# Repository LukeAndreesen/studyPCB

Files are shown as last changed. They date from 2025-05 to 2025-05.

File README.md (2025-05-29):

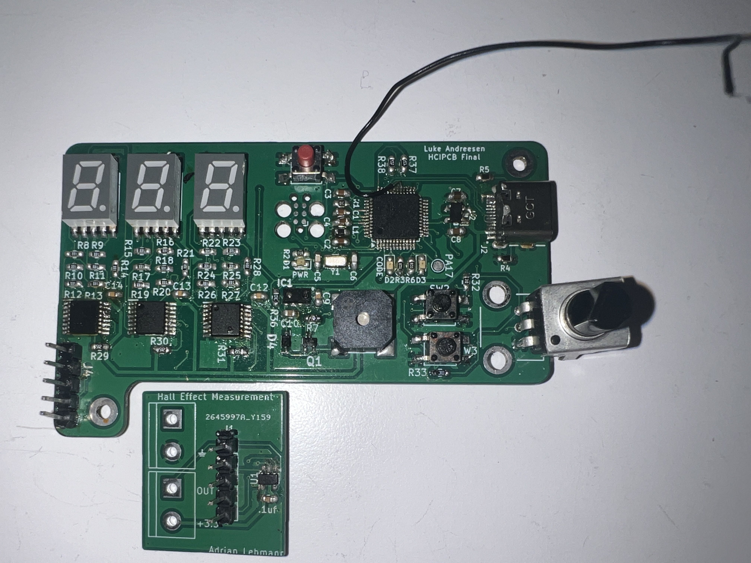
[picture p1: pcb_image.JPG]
PCB Image


This project is a study timer that is meant to enforce productivity; an onboard
IR sensor, as well as a daughter-board hall-effect sensor module detect
a user's presence and ensure their phone is sitting on the desk and not in 
their hands. 3 daisy-chaineed shift registers control the 7-segment displays, 
and a magnetic buzzer and onboard LED's provide feedback and alerts. The 
devce connects to the user's computer via USB for power and serial connectivity
with the UI which can be interacted with using the board's buttons and 
potentiometer dial. This was my first independent PCB board, and I really
enjoyed the process of designing, soldering, and programming it!

A Bill of Materials is available as CSV in this repo, along with KiCad schematics.

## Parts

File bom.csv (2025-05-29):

Reference | Value | Datasheet | Footprint | Qty | DNP
C1,C2,C3,C4 | 0.1uF | ~ | Capacitor_SMD:C_0603_1608Metric_Pad1.08x0.95mm_HandSolder | 4
C5,C6 | 22pF | ~ | Capacitor_SMD:C_0603_1608Metric_Pad1.08x0.95mm_HandSolder | 2
C7,C8 | 1uF | ~ | Capacitor_SMD:C_0603_1608Metric_Pad1.08x0.95mm_HandSolder | 2
C9,C12,C13,C14 | 100nF | ~ | Capacitor_SMD:C_0603_1608Metric_Pad1.08x0.95mm_HandSolder | 4
C10 | 470nF | ~ | Capacitor_SMD:C_0603_1608Metric_Pad1.08x0.95mm_HandSolder | 1
C15 | 100nF | ~ | Capacitor_SMD:C_0603_1608Metric_Pad1.08x0.95mm_HandSolder | 1 | DNP
D1 | GREEN | ~ | LED_SMD:LED_0603_1608Metric_Pad1.05x0.95mm_HandSolder | 1
D2,D3 | RED | ~ | LED_SMD:LED_0603_1608Metric_Pad1.05x0.95mm_HandSolder | 2
D4 | D | https://www.vishay.com/docs/85751/1n4148ws.pdf | finalpcb:SOD2713X115N | 1
DS1,DS2,DS3 | 157112V12700 | https://componentsearchengine.com/Datasheets/2/157112V12700.pdf | finalpcb:157112V12700 | 3
IC1 | VCNL3040 | https://www.vishay.com/docs/84917/vcnl3040.pdf | finalpcb:SON108P200X400X115-8N | 1
IC2,IC3,IC4 | 74HC595PW-Q100,118 | https://assets.nexperia.com/documents/data-sheet/74HC_HCT595_Q100.pdf | finalpcb:SOP65P640X110-16N | 3
IC5 | Si7210-B-04-IVR | https://componentsearchengine.com/Datasheets/2/SI7210-B-04-IVR.pdf | finalpcb:SOT95P275X125-5N | 1 | DNP
J1 | SWD_TAG-CONNECT | https://www.tag-connect.com/wp-content/uploads/bsk-pdf-manager/TC2030-CTX_1.pdf | Connector:Tag-Connect_TC2030-IDC-FP_2x03_P1.27mm_Vertical | 1
J2 | USB4105-GF-A | https://www.mouser.com/datasheet/2/837/Global_Connector_Technology_usb4105-3106202.pdf | hcipcb:GCT_USB4105-GF-A | 1
J4 | 10129379-905001BLF | https://cdn.amphenol-cs.com/media/wysiwyg/files/drawing/10129379.pdf | HDRRA5W67P0X254_1X5_1270X254X241P | 1
L1 | FB-30R | https://www.mouser.com/ProductDetail/Laird-Performance-Materials/MI0603K300R-10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 | Inductor_SMD:L_0603_1608Metric_Pad1.05x0.95mm_HandSolder | 1
LS3 | CMT-8504-03-SMT-TR | https://www.sameskydevices.com/product/resource/cmt-8504-03-smt-tr.pdf | CMT850403SMTTR | 1
PA17 | TestPoint | ~ | TestPoint:TestPoint_Pad_D1.5mm | 1
Q1 | Q_NPN_BCE | https://www.mouser.com/datasheet/2/408/2SA1588_datasheet_en_20210625-1140114.pdf | finalpcb:2SA1588GRLF | 1
R1,R32,R33,R36 | 10k | ~ | Resistor_SMD:R_0603_1608Metric_Pad0.98x0.95mm_HandSolder | 4
R2,R3,R6 | 1k | ~ | Resistor_SMD:R_0603_1608Metric_Pad0.98x0.95mm_HandSolder | 3
R4,R5,R29,R30,R31 | 5.1k | ~ | Resistor_SMD:R_0603_1608Metric_Pad0.98x0.95mm_HandSolder | 5
R7 | 180 | ~ | Resistor_SMD:R_0603_1608Metric_Pad0.98x0.95mm_HandSolder | 1
R8,R9,R10,R11,R12,R13,R14,R15,R16,R17,R18,R19,R20,R21,R22,R23,R24,R25,R26,R27,R28 | 330 | ~ | Resistor_SMD:R_0603_1608Metric_Pad0.98x0.95mm_HandSolder | 21
R37,R38 | 4.7k | ~ | Resistor_SMD:R_0603_1608Metric_Pad0.98x0.95mm_HandSolder | 2
SW1,SW2,SW3 | SW_Push | ~ | Button_Switch_SMD:SW_SPST_TL3305A | 3
U1 | ATSAMD21G18A-A | http://ww1.microchip.com/downloads/en/DeviceDoc/SAM_D21_DA1_Family_Data%20Sheet_DS40001882E.pdf | Package_QFP:TQFP-48_7x7mm_P0.5mm | 1
U2 | TLV73333PQDBVRQ1 | http://www.ti.com/lit/gpn/TLV733P-Q1 | hcipcb:SOT95P280X145-5N | 1
VR1 | PT01-B115D-B103 | https://www.sameskydevices.com/product/resource/supplyframepdf/pt01-b120d-b103.pdf | finalpcb:PT01B115DB103 | 1
Y1 | Crystal_Small | ~ | Crystal:Crystal_SMD_3215-2Pin_3.2x1.5mm | 1

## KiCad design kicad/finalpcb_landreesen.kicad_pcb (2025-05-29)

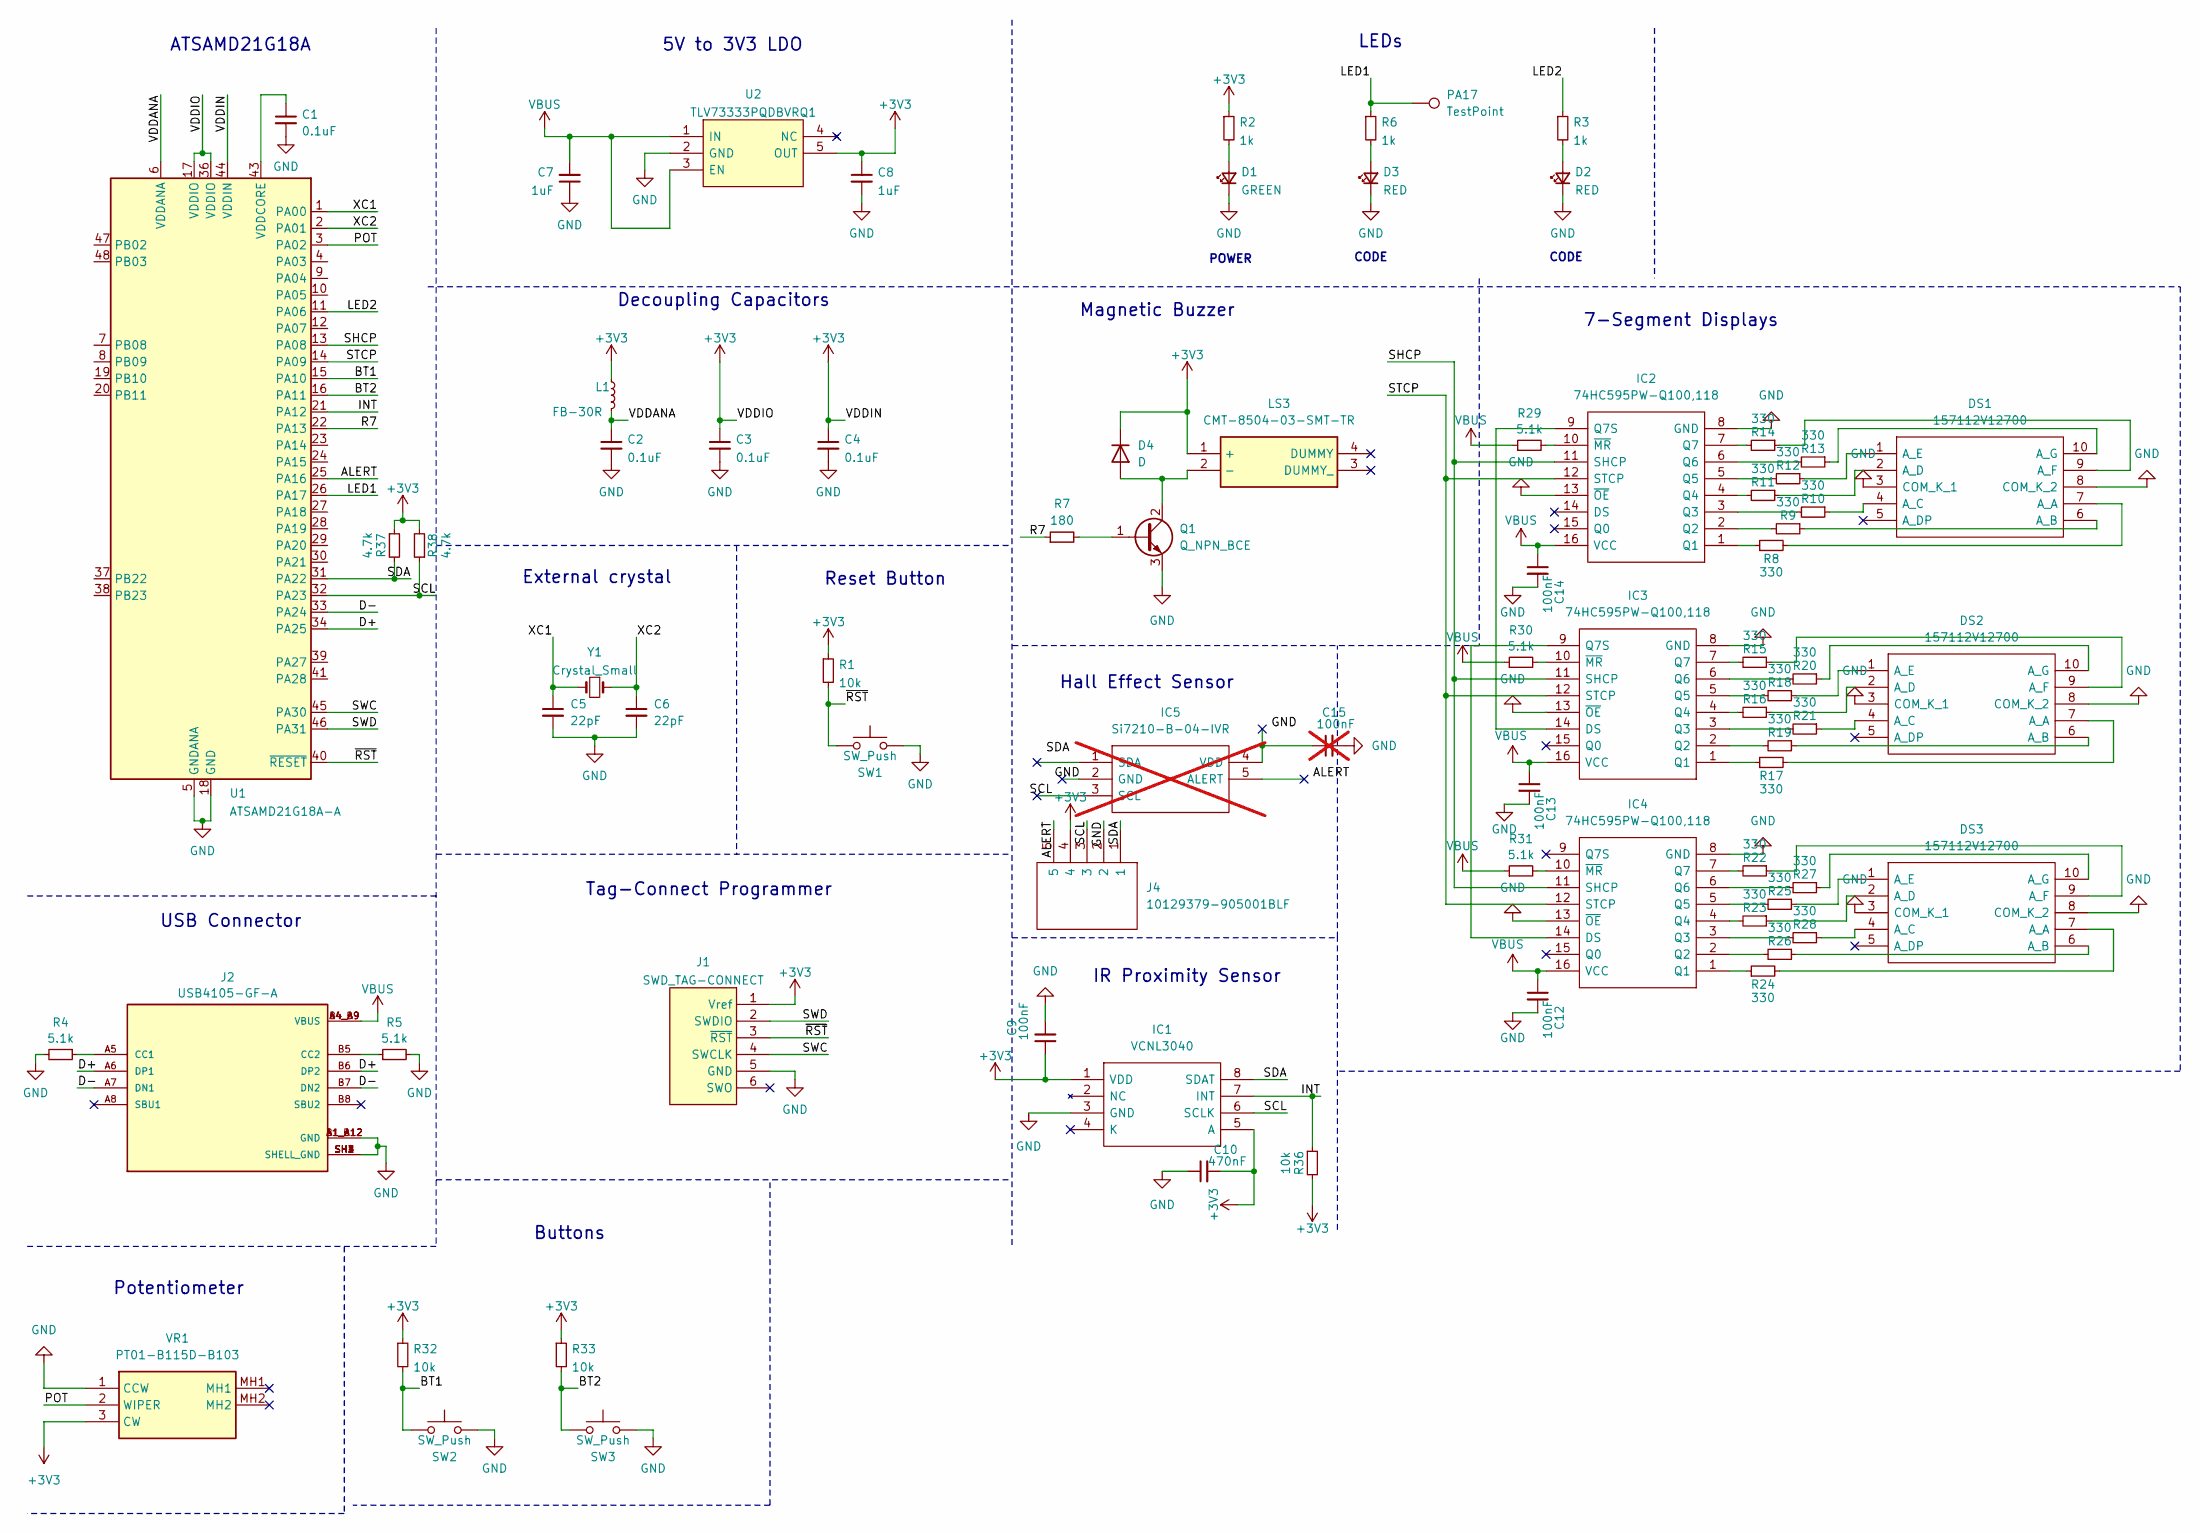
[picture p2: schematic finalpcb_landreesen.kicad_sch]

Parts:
C1, C2, C3, C4: 0.1uF; C_0603_1608Metric_Pad1.08x0.95mm_HandSolder
C5, C6: 22pF; C_0603_1608Metric_Pad1.08x0.95mm_HandSolder; Mouser Part Number 581-06035C220JAT2A
C7, C8: 1uF; C_0603_1608Metric_Pad1.08x0.95mm_HandSolder
C9, C12, C13, C14: 100nF; C_0603_1608Metric_Pad1.08x0.95mm_HandSolder
C10: 470nF; C_0603_1608Metric_Pad1.08x0.95mm_HandSolder
C15: 100nF; C_0603_1608Metric_Pad1.08x0.95mm_HandSolder; not fitted
D1: GREEN; LED_0603_1608Metric_Pad1.05x0.95mm_HandSolder
D2, D3: RED; LED_0603_1608Metric_Pad1.05x0.95mm_HandSolder; Mouser Part Number 710-150060RS55040
D4: D; SOD2713X115N
DS1, DS2, DS3: 157112V12700; Mouser Part Number 710-157112V12700
IC1: VCNL3040; SON108P200X400X115-8N; Mouser Part Number 78-VCNL3040
IC2, IC3, IC4: 74HC595PW-Q100,118; SOP65P640X110-16N; Mouser Part Number 771-74HC595PW-Q100
IC5: Si7210-B-04-IVR; SOT95P275X125-5N; Mouser Part Number 634-SI7210-B-04-IVR; not fitted
J1: SWD_TAG-CONNECT; Tag-Connect_TC2030-IDC-FP_2x03_P1.27mm_Vertical
J2: USB4105-GF-A; GCT_USB4105-GF-A
J4: 10129379-905001BLF; HDRRA5W67P0X254_1X5_1270X254X241P; Manufacturer_Part_Number 10129379-905001BLF
L1: FB-30R; L_0603_1608Metric_Pad1.05x0.95mm_HandSolder
LS3: CMT-8504-03-SMT-TR; CMT850403SMTTR; Mouser Part Number 179-CMT-8504-03SMTTR
PA17: TestPoint; TestPoint_Pad_D1.5mm
Q1: Q_NPN_BCE; 2SA1588GRLF
R1, R32, R33, R36: 10k; R_0603_1608Metric_Pad0.98x0.95mm_HandSolder
R2, R3, R6: 1k; R_0603_1608Metric_Pad0.98x0.95mm_HandSolder
R4, R5, R29, R30, R31: 5.1k; R_0603_1608Metric_Pad0.98x0.95mm_HandSolder
R7: 180; R_0603_1608Metric_Pad0.98x0.95mm_HandSolder
R8, R9, R10, R11, R12, R13, R14, R15, R16, R17, R18, R19, R20, R21, R22, R23, R24, R25, R26, R27, R28: 330; R_0603_1608Metric_Pad0.98x0.95mm_HandSolder
R37, R38: 4.7k; R_0603_1608Metric_Pad0.98x0.95mm_HandSolder
SW1, SW2, SW3: SW_Push; SW_SPST_TL3305A
U1: ATSAMD21G18A-A; TQFP-48_7x7mm_P0.5mm
U2: TLV73333PQDBVRQ1; SOT95P280X145-5N; Mouser Part Number 595-TLV73333PQDBVRQ1
VR1: PT01-B115D-B103; PT01B115DB103; Mouser Part Number 179-PT01-B115D-B103
Y1: Crystal_Small; Crystal_SMD_3215-2Pin_3.2x1.5mm; Mouser Part Number 815-ABS07-32.768KHZT

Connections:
+3V3: C3.1, C4.1, C8.1, C9.1, C10.2, D4.1 (K), IC1.1 (VDD), IC1.5 (A), J1.1 (Vref), J4.4, L1.1, LS3.1 (+), R1.1, R2.1, R32.1, R33.1, R36.2, R37.1, R38.2, U1.17 (VDDIO), U1.36 (VDDIO), U1.44 (VDDIN), U2.5 (OUT), VR1.3 (CW)
/ALERT: J4.5, U1.25 (PA16)
/BT1: R32.2, SW2.1, U1.15 (PA10)
/BT2: R33.2, SW3.1, U1.16 (PA11)
/D+: J2.A6 (DP1), J2.B6 (DP2), U1.34 (PA25)
/D-: J2.A7 (DN1), J2.B7 (DN2), U1.33 (PA24)
/INT: IC1.7 (INT), R36.1, U1.21 (PA12)
/LED1: PA17.1, R6.1, U1.26 (PA17)
/LED2: R3.1, U1.11 (PA06)
/POT: U1.3 (PA02), VR1.2 (WIPER)
/R7: R7.1, U1.22 (PA13)
/SCL: IC1.6 (SCLK), J4.3, R38.1, U1.32 (PA23)
/SDA: IC1.8 (SDAT), J4.1, R37.2, U1.31 (PA22)
/SHCP: IC2.11 (SHCP), IC3.11 (SHCP), IC4.11 (SHCP), U1.13 (PA08)
/STCP: IC2.12 (STCP), IC3.12 (STCP), IC4.12 (STCP), U1.14 (PA09)
/SWC: J1.4 (SWCLK), U1.45 (PA30)
/SWD: J1.2 (SWDIO), U1.46 (PA31)
/VDDANA: C2.1, L1.2, U1.6 (VDDANA)
/XC1: C5.1, U1.1 (PA00), Y1.2
/XC2: C6.1, U1.2 (PA01), Y1.1
/~RST: J1.3 (~RST), R1.2, SW1.1, U1.40 (~RESET)
GND: C1.2, C2.2, C3.2, C4.2, C5.2, C6.2, C7.1, C8.2, C9.2, C10.1, C12.2, C13.2, C14.2, C15.2, D1.1 (K), D2.1 (K), D3.1 (K), DS1.3 (COM_K_1), DS1.8 (COM_K_2), DS2.3 (COM_K_1), DS2.8 (COM_K_2), DS3.3 (COM_K_1), DS3.8 (COM_K_2), IC1.3 (GND), IC2.8 (GND), IC2.13 (~OE), IC3.8 (GND), IC3.13 (~OE), IC4.8 (GND), IC4.13 (~OE), J1.5 (GND), J2.A1_B12 (GND), J2.B1_A12 (GND), J2.SH1 (SHELL_GND), J2.SH2 (SHELL_GND), J2.SH3 (SHELL_GND), J2.SH4 (SHELL_GND), J4.2, Q1.3 (E), R4.2, R5.2, SW1.2, SW2.2, SW3.2, U1.5 (GNDANA), U1.18 (GND), U1.35 (GND), U1.42 (GND), U2.2 (GND), VR1.1 (CCW)
unnamed: C15.1, IC5.4 (VDD)
unnamed: D1.2 (A), R2.2
unnamed: D2.2 (A), R3.2
unnamed: D3.2 (A), R6.2
unnamed: D4.2 (A), LS3.2 (-), Q1.2 (C)
unnamed: DS1.7 (A_A), R8.2
unnamed: DS1.6 (A_B), R9.1
unnamed: DS1.4 (A_C), R10.1
unnamed: DS1.2 (A_D), R11.1
unnamed: DS1.1 (A_E), R12.1
unnamed: DS1.9 (A_F), R14.1
unnamed: DS1.10 (A_G), R13.1
unnamed: DS2.7 (A_A), R17.2
unnamed: DS2.6 (A_B), R19.1
unnamed: DS2.4 (A_C), R21.1
unnamed: DS2.2 (A_D), R16.1
unnamed: DS2.1 (A_E), R18.1
unnamed: DS2.9 (A_F), R15.1
unnamed: DS2.10 (A_G), R20.1
unnamed: DS3.7 (A_A), R24.2
unnamed: DS3.6 (A_B), R26.1
unnamed: DS3.4 (A_C), R28.1
unnamed: DS3.2 (A_D), R23.1
unnamed: DS3.1 (A_E), R25.1
unnamed: DS3.9 (A_F), R22.1
unnamed: DS3.10 (A_G), R27.1
unnamed: IC2.1 (Q1), R8.1
unnamed: IC2.2 (Q2), R9.2
unnamed: IC2.3 (Q3), R10.2
unnamed: IC2.4 (Q4), R11.2
unnamed: IC2.5 (Q5), R12.2
unnamed: IC2.6 (Q6), R13.2
unnamed: IC2.7 (Q7), R14.2
unnamed: IC2.9 (Q7S), IC3.14 (DS)
unnamed: IC2.10 (~MR), R29.2
unnamed: IC3.1 (Q1), R17.1
unnamed: IC3.2 (Q2), R19.2
unnamed: IC3.3 (Q3), R21.2
unnamed: IC3.4 (Q4), R16.2
unnamed: IC3.5 (Q5), R18.2
unnamed: IC3.6 (Q6), R20.2
unnamed: IC3.7 (Q7), R15.2
unnamed: IC3.9 (Q7S), IC4.14 (DS)
unnamed: IC3.10 (~MR), R30.2
unnamed: IC4.1 (Q1), R24.1
unnamed: IC4.2 (Q2), R26.2
unnamed: IC4.3 (Q3), R28.2
unnamed: IC4.4 (Q4), R23.2
unnamed: IC4.5 (Q5), R25.2
unnamed: IC4.6 (Q6), R27.2
unnamed: IC4.7 (Q7), R22.2
unnamed: IC4.10 (~MR), R31.2
unnamed: J2.A5 (CC1), R4.1
unnamed: J2.B5 (CC2), R5.1
unnamed: Q1.1 (B), R7.2
unnamed: C1.1, U1.43 (VDDCORE)
VBUS: C7.2, C12.1, C13.1, C14.1, IC2.16 (VCC), IC3.16 (VCC), IC4.16 (VCC), J2.A4_B9 (VBUS), J2.B4_A9 (VBUS), R29.1, R30.1, R31.1, U2.1 (IN), U2.3 (EN)

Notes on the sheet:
Buttons
5V to 3V3 LDO
External crystal
Tag-Connect Programmer
Decoupling Capacitors
Magnetic Buzzer
CODE
7-Segment Displays
LEDs
IR Proximity Sensor
POWER
Hall Effect Sensor
USB Connector
Potentiometer
ATSAMD21G18A
Reset Button

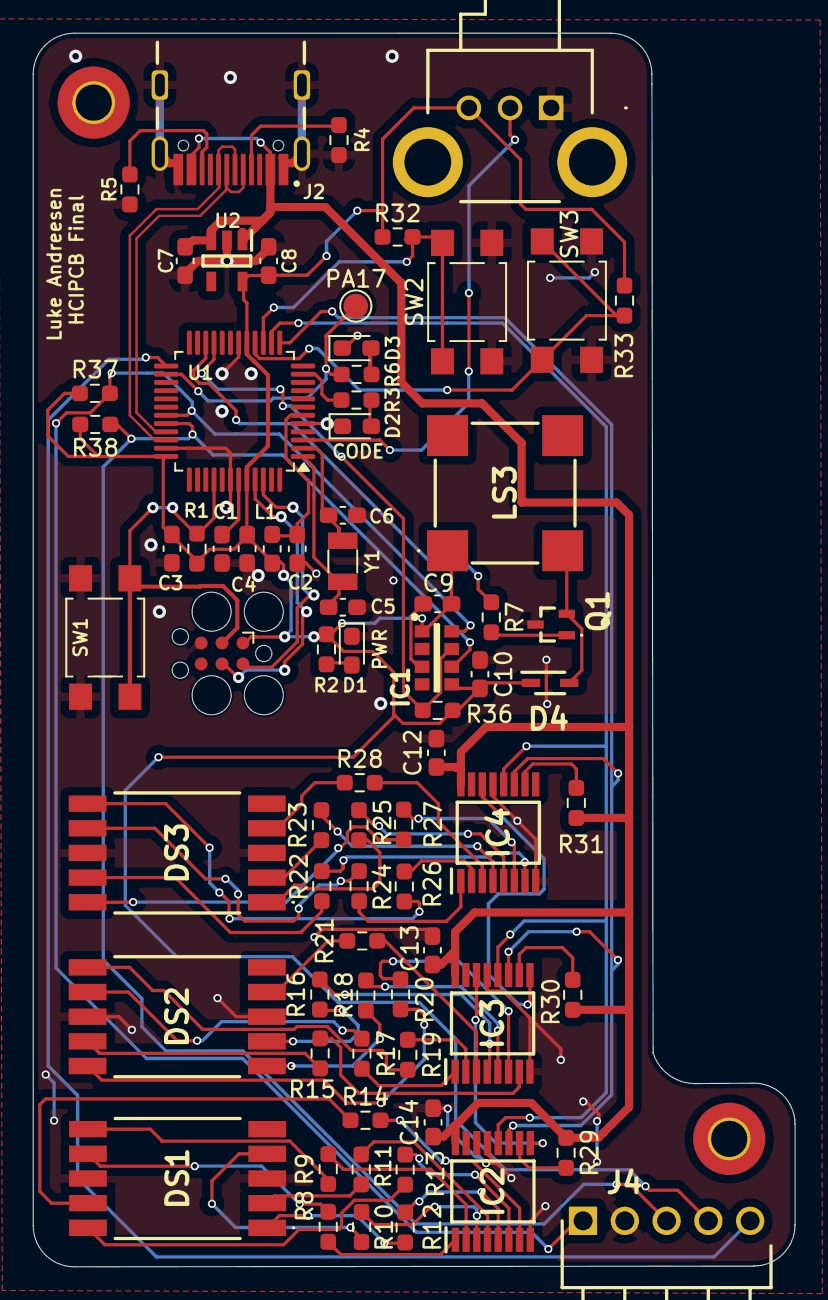
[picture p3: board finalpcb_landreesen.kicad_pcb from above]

Board: 2 copper layers, 46.3 x 75.0 mm, 74 parts (0 on the bottom side), 78 nets.

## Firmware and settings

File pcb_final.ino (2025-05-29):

#include <Wire.h>
#include "VCNL3040.h"
#include "si7210.h"  
/*
SOURCES:
  [1] https://www.youtube.com/watch?v=QI1IJLB42G8 - used for all shift register logic!
  [2] https://chatgpt.com/share/68372485-d47c-8005-8657-77b860ad0506 - used chatgpt to help me learn about receiving/parsing serialusb 
  [3] https://github.com/FARLY7/si7210-driver - si7210 driver library
*/

VCNL3040 proximitySensor;

// timer tracking ()
bool TIMER_STARTED = false;


// SI7210 device structure
si7210_dev_t hallSensor;
bool si7210_working = false;  // Track if SI7210 is working

const int histSize = 10;
const float MAG_THRESH = 0.40;
const int PROX_THRESH = 3; // 7 of the last 10 readings should be nonzero
const int POT = A0;
const int CODE_LED = 40;
const int HALL_LED = 41;  // Add a second LED for hall sensor indication
const int BUZZER = 38;
const int DS = 6;
const int SHCP = 4;
const int STCP = 3;
const int BT1 = 1;
const int BT2 = 0;

uint16_t prevProx[histSize] = {0};
int proxIdx = 0;
bool userPresent = true;
bool phoneDetected = true;

// Source: [1]
// decimal representation of 7 segment display values
int digits[10] = {126, 48, 109, 121, 51, 91, 95, 112, 127, 123}; // ideally used for display ... didn't work :(

void displayTest(){
  // SOURCE: [1]
  // Ideally ths would iterate through all numbers on each screen ... but doesn't work
  for (int k = 0; k < 10; k++) {       // Left digit
    for (int j = 0; j < 10; j++) {     // middle digit
      for (int i = 0; i < 10; i++) {   // Right digit
        digitalWrite(STCP, LOW);
        shiftOut(DS, SHCP, LSBFIRST, digits[i]);  // Right
        shiftOut(DS, SHCP, LSBFIRST, digits[j]);  // Middle
        shiftOut(DS, SHCP, LSBFIRST, digits[k]);  // Lef
        digitalWrite(STCP, HIGH);
        delay(200);
      }
    }
  }
}

int getPotVal(int pot_reading) {
  // read potentiometer
  float range_val = 1023.0 / 10; // potentonmeter goes up to 1023, want one of 10 values
  int val = pot_reading / 102.4;  
  if (val > 9){
    val = 9; // just in case it somehow exceeds 9
  }
  return val;
}

void checkSerialCommands() {
  // Listens for serial commands from our application to start/stop timer
  // Source: [2]
  if (SerialUSB.available()) {
    String cmd = SerialUSB.readStringUntil('\n');
    cmd.trim();

    if (cmd == "TIMER_START") {
      SerialUSB.println("Timer started!");
      // Single beep - timer started
      tone(BUZZER, 2000);   
      delay(200);
      noTone(BUZZER);
      TIMER_STARTED = true;    
    } 
    else if (cmd == "TIMER_END") {
      // Double beep - timer done
      SerialUSB.println("Timer ended!");
      TIMER_STARTED = false; 
      tone(BUZZER, 1500);   
      delay(400);
      noTone(BUZZER); 
      delay(300);
      tone(BUZZER, 1500);   
      delay(400);
      noTone(BUZZER); 
    }
  }
}


// I2C communication functions for SI7210
si7210_status_t i2c_read(uint8_t dev_id, uint8_t reg_addr, uint8_t *data, uint16_t len) {
  // Source: [3] - taken straight from examples
  Wire.beginTransmission(dev_id >> 1);  // converts to copmatible adress form (7-bit)
  Wire.write(reg_addr);
  if (Wire.endTransmission() != 0) {
    return SI7210_E_IO;
  }
  
  Wire.requestFrom((uint8_t)(dev_id >> 1), len);
  for (uint16_t i = 0; i < len; i++) {
    if (Wire.available()) {
      data[i] = Wire.read();
    } else {
      return SI7210_E_IO;
    }
  }
  return SI7210_OK;
}

si7210_status_t i2c_write(uint8_t dev_id, uint8_t reg_addr, uint8_t *data, uint16_t len) {
  // Source: [3] - taken straight from examples
  Wire.beginTransmission(dev_id >> 1);  // converts to copmatible adress form (7-bit)
  Wire.write(reg_addr);
  for (uint16_t i = 0; i < len; i++) {
    Wire.write(data[i]);
  }
  if (Wire.endTransmission() != 0) {
    return SI7210_E_IO;
  }
  return SI7210_OK;
}

void delay_ms(uint32_t period) {
  // Used for si7210 setup (via examples [3])
  delay(period);
}

void setup_proximity()
{
  // Initialize VCNL3040 proximity sensor 
  if (!proximitySensor.begin()) {
    SerialUSB.println("VCNL3040 not found");
    while (1);
  }
  SerialUSB.println("VCNL3040 initialized.");
  proximitySensor.startReading(); // now let's start reading proximty data
}

void setup_hall()
{
  // Initialize SI7210 hall effect sensor - via [3]
  hallSensor.dev_id = 0x33 << 1;  // Convert to 8-bit address for library
  // reference functions setup as per [3]
  hallSensor.read = i2c_read;
  hallSensor.write = i2c_write;
  hallSensor.delay_ms = delay_ms;
  hallSensor.threshold_callback = NULL; // not needed
  
  // Set sensor settings - as per [3]
  hallSensor.settings.range = SI7210_200mT;  // 200mT range
  hallSensor.settings.compensation = SI7210_COMPENSATION_NONE;
  hallSensor.settings.output_pin = SI7210_OUTPUT_PIN_LOW;

  // Initialize the SI7210 sensor [3]
  SerialUSB.println("Initializing SI7210 hall effect sensor");
  si7210_status_t result = si7210_init(&hallSensor);
  SerialUSB.print("Initialization result: ");
  SerialUSB.println(result);
    
  // build in redundancy - if it's not working, or detached, we should continue
  if (result != SI7210_OK) {
    SerialUSB.print("SI7210 initialization failed. Error code:");
    SerialUSB.println(result);
    SerialUSB.println("We will proceed without the hall effect sensor");
    si7210_working = false;
  } 
  else {
    SerialUSB.println("SI7210 initialized successfully!");
    si7210_working = true;
  }
}

void setup() {
  // LED's for debuggin
  pinMode(CODE_LED, OUTPUT);
  pinMode(HALL_LED, OUTPUT); 
  // pins for shift registers for display
  pinMode(DS, OUTPUT);
  pinMode(SHCP, OUTPUT);
  pinMode(STCP, OUTPUT);
  // button pins .. didn't end up using though
  pinMode(BT1, INPUT);
  pinMode(BT2, INPUT);
  
  SerialUSB.begin(9600);
  while (!SerialUSB); // let serial usb setup first

  // Initialize I2C
  Wire.begin();

  // setup sensors
  setup_proximity();
  setup_hall();

  SerialUSB.println("Setup complete. Starting main loop...");
  delay(5000); // a delay to get set up
}

void loop() {
  checkSerialCommands(); // check for timer start/stop via web app
  // Read proximity sensor
  uint16_t proximity = proximitySensor.readPSData();
  
  // Read potentiometer
  int pot_reading = analogRead(POT);
  int pot_val = getPotVal(pot_reading);
  SerialUSB.print("Dial Value: ");
  SerialUSB.print(pot_val);
  SerialUSB.print(" | ");


  
  // Only try to read hall sensor if it's working - suggested in [3]
  float magneticField = 0.0;
  si7210_status_t result = SI7210_E_DEV_NOT_FOUND;
  
  // result will be SI7210_OK if reading works and saved to magneticField, else something went wrong
  if (si7210_working) {
    result = si7210_get_field_strength(&hallSensor, &magneticField);
  }
  
  if (result != SI7210_OK) {
    SerialUSB.println("N/A (SI7210 not available)");
  
  }
  // any singnificant change in magnetic field (+ or -) should be detected (phone is next to sensor)
  if (abs(magneticField) < MAG_THRESH)
  {
    SerialUSB.print("Phone: False |");
    phoneDetected = false;
  }
  else
  {
     SerialUSB.print("Phone: True | ");
     phoneDetected = true;
  }

  // If we have started timer and we move away from desk or move phone ...  BUZZ!
  if (TIMER_STARTED)
  {
    (phoneDetected & (proximity >= 5)) ? noTone(BUZZER) : tone(BUZZER, 4000);
  }
  
  // unused logic -- ideally we'd make the proxmity software a bit more robust to account for sensor sensitivity
  prevProx[proxIdx] = proximity;
  proxIdx = (proxIdx + 1) % 10; // we want to look at previous 10 readings

  // Count how many of the last 10 readings are zero
  int num_zeros = 0;
  for (int i = 0; i < histSize; i++) {
    if ((prevProx[i] == 0) or (prevProx[i] == 1))  {
      num_zeros++;
    }
  }

  // we have moved away from desk 
  if (proximity < 5){
    userPresent = false;
    SerialUSB.println(" At desk: False");
  }
  else
  {
    userPresent = true;
    SerialUSB.println(" At desk: True");
  }


  delay(100); // give a slight timing gap
}
